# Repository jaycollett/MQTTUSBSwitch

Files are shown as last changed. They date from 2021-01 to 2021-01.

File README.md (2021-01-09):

# MQTTUSBSwitch
 

MQTT Enabled USB Switch to remotely connect/disconnect USB devices. This firmware and hardware attempts to mimic the actual pin connect/disconnect sequence that occurs when physically inserting or removing a USB plug. The board uses USB 3.0 connectors but only supports USB 2.0. Future versions will correctly switch the extra SS data pins so it will support USB 3.0. 

# Schematic 
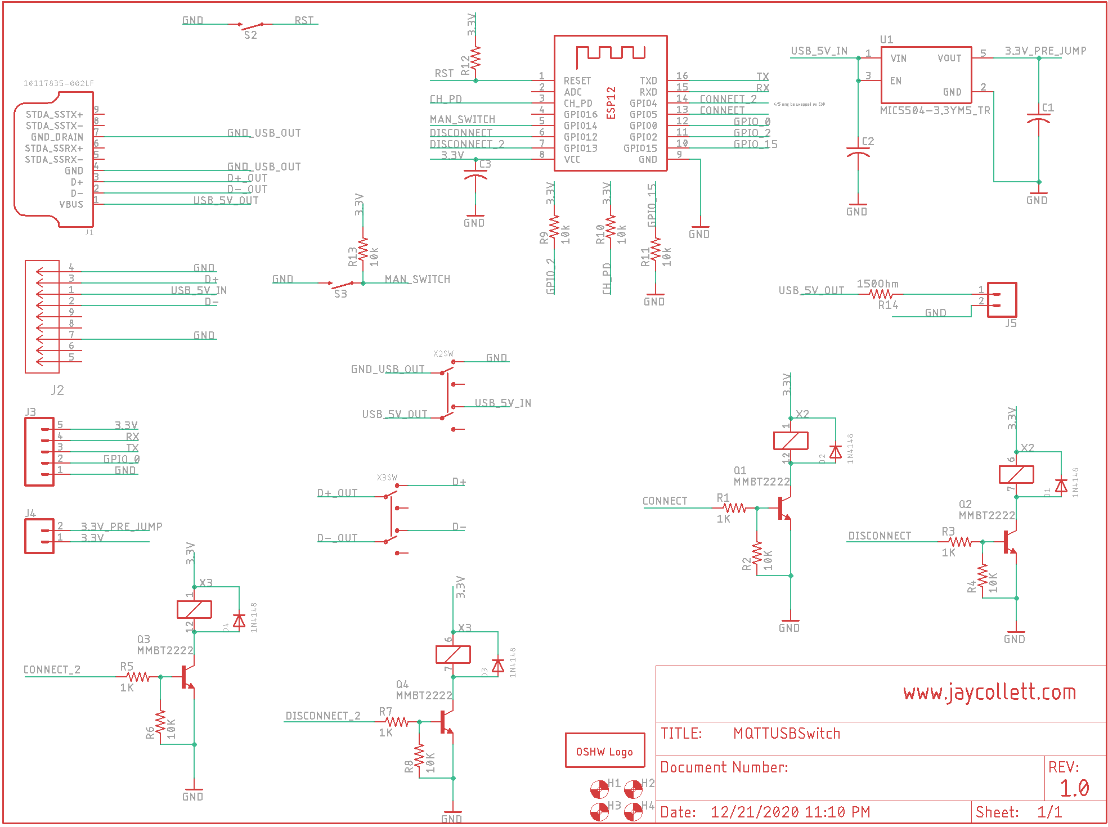
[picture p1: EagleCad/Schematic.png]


# Board 
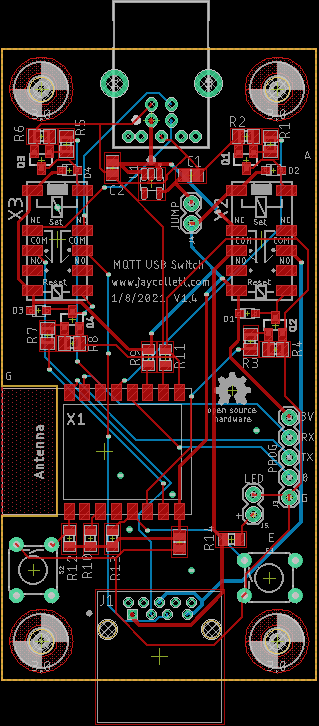
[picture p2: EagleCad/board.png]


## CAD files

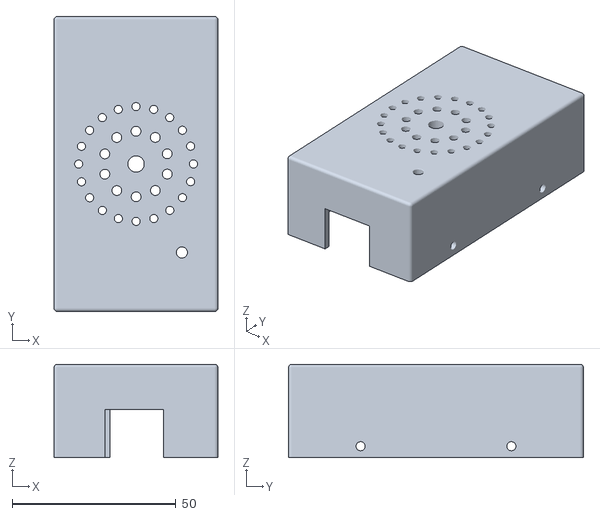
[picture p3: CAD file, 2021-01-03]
Project Enclosure/MQTTUSBSwitchCaseTopv2.stl
50.0 x 90.0 x 28.5

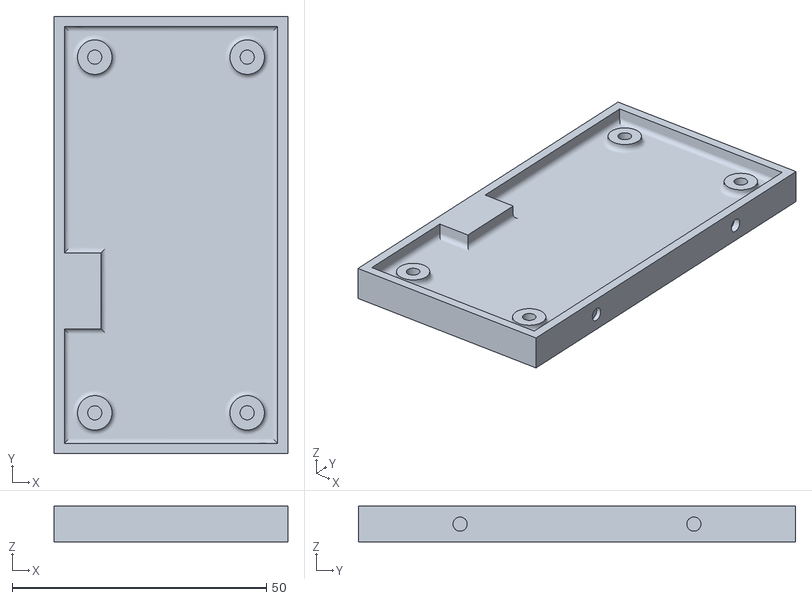
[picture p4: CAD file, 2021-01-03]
Project Enclosure/MQTTUSBSwitchCaseBottomv2.stl
46.0 x 86.0 x 7.05

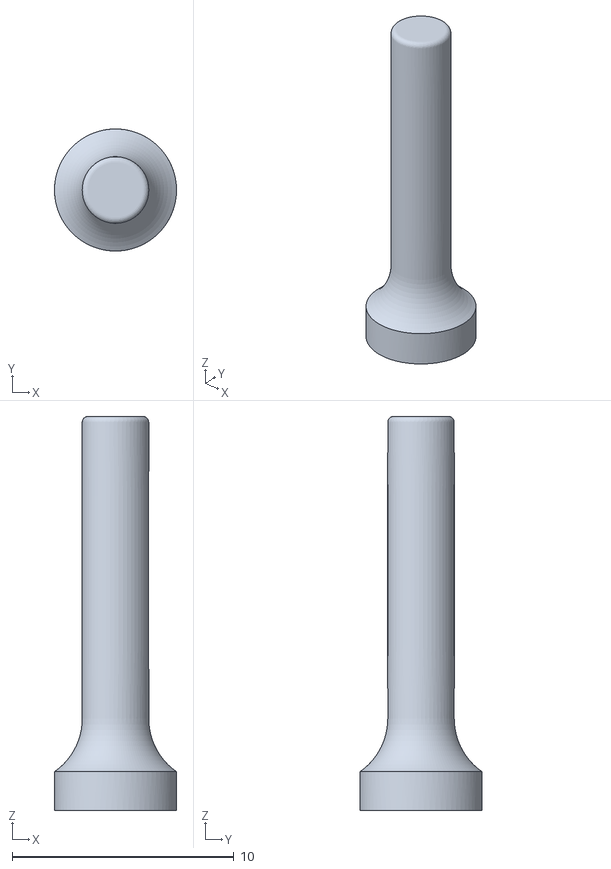
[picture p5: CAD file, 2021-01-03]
Project Enclosure/MQTTUSBSwitchPlunger.stl
5.50 x 5.50 x 17.7

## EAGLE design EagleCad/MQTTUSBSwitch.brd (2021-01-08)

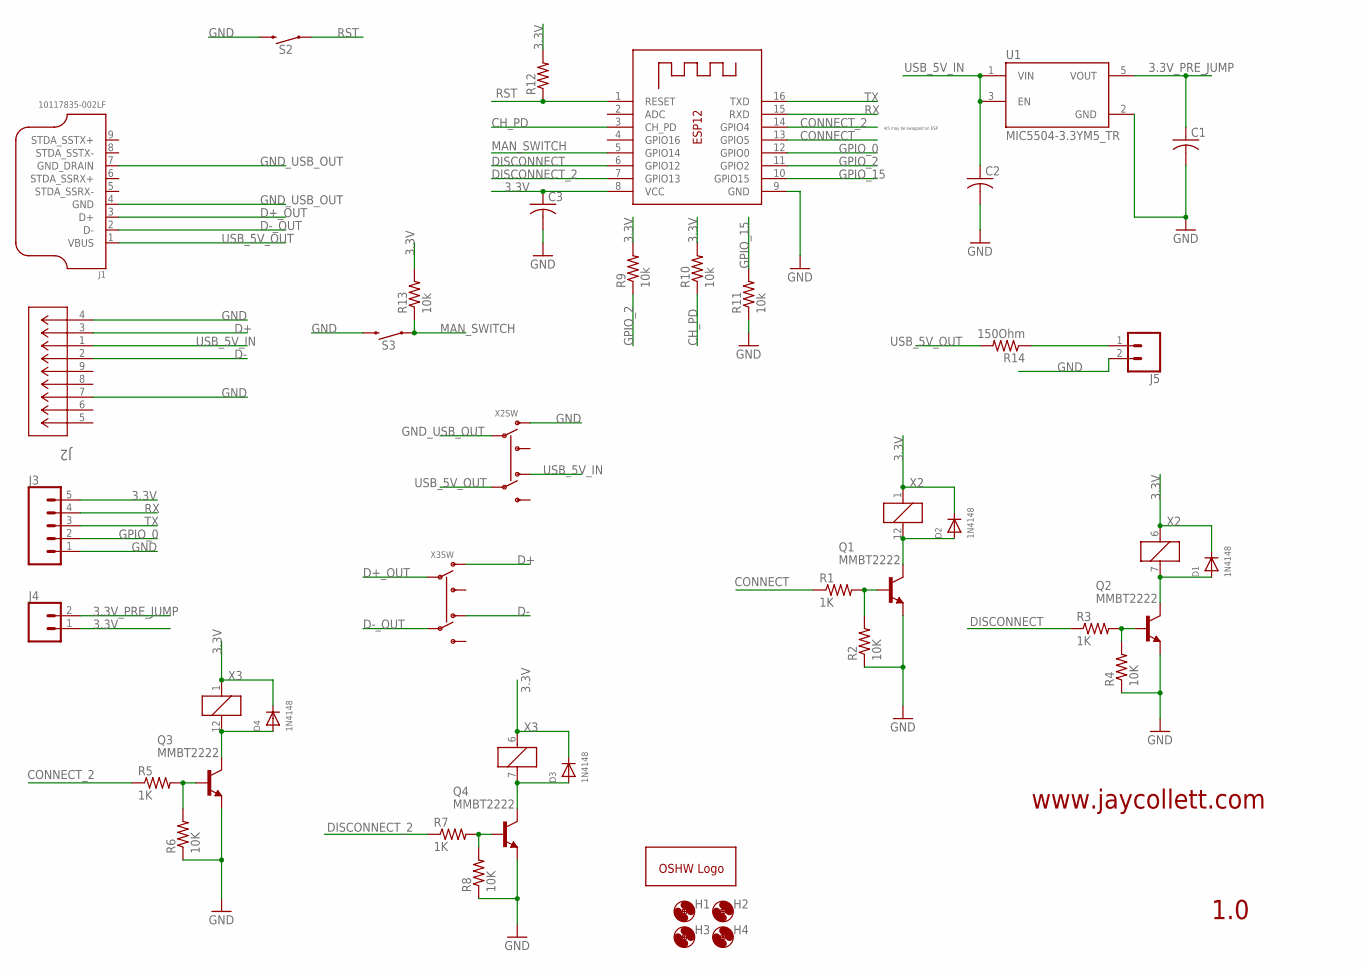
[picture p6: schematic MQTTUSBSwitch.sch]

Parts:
C1, C2, C3: C-USC0805; C0805
D1, D2, D3, D4: 1N4148; SOD-323F
GOLD_ORB_SM1: OSHWLOGOLOGO5MM; OSHW_5MM
H1, H2, H3, H4: MOUNT-HOLE3.0; 3,0
J1: 10117835-002LF; FCI_10117835-002LF
J2: GSB4211311WEU; CONN9_1311WEU_AMP
J3: CONN_05; 1X05
J4, J5: CONN_02; 1X02
Q1, Q2, Q3, Q4: MMBT2222; SOT23-BEC
R1, R3, R5, R7: 1K; M0805
R2, R4, R6, R8: 10K; M0805
R9, R10, R11, R13: 10k; R0805
R12: R-US_R0805; R0805
R14: 150Ohm; R0805
S2, S3: MOMENTARY-SWITCH-SPST-PTH-6.0MM-KIT; TACTILE_SWITCH_PTH_6.0MM_KIT
U1: MIC5504-3.3YM5_TR; SOT95P280X145-5N
X1: ESP-12
X2, X3: MICROBUILDER_RELAY_LATCHINGEE2NUH; MICROBUILDER_RELAY_EE2_LATCH

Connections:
3.3V: C3.1, D1.C, D2.C, D3.C, D4.C, J3.5, J4.1, R9.2, R10.2, R12.2, R13.2, X1.8 (VCC), X2.1, X2.6 (1), X3.1, X3.6 (1)
3.3V_PRE_JUMP: C1.1, J4.2, U1.5 (VOUT)
CH_PD: R10.1, X1.3 (CH_PD)
CONNECT: R1.1, X1.13 (GPIO5)
CONNECT_2: R5.1, X1.14 (GPIO4)
D+: J2.3, X3.10 (O1)
D+_OUT: J1.3 (D+), X3.9 (P1)
D-: J2.2, X3.3 (O2)
D-_OUT: J1.2 (D-), X3.4 (P2)
DISCONNECT: R3.1, X1.6 (GPIO12)
DISCONNECT_2: R7.1, X1.7 (GPIO13)
GND: C1.2, C2.2, C3.2, J2.4, J2.7, J3.1, J5.2, Q1.E, Q2.E, Q3.E, Q4.E, R2.1, R4.1, R6.1, R8.1, R11.1, S2.3 (2), S3.3 (2), U1.2 (GND), X1.9 (GND), X2.10 (O1)
GND_USB_OUT: J1.4 (GND), J1.7 (GND_DRAIN), X2.9 (P1)
GPIO_0: J3.2, X1.12 (GPIO0)
GPIO_2: R9.1, X1.11 (GPIO2)
GPIO_15: R11.2, X1.10 (GPIO15)
MAN_SWITCH: R13.1, S3.1, X1.5 (GPIO14)
unnamed: J5.1, R14.1
unnamed: D2.A, Q1.C, X2.12 (2)
unnamed: D1.A, Q2.C, X2.7 (2)
unnamed: Q1.B, R1.2, R2.2
unnamed: Q2.B, R3.2, R4.2
unnamed: D4.A, Q3.C, X3.12 (2)
unnamed: D3.A, Q4.C, X3.7 (2)
unnamed: Q3.B, R5.2, R6.2
unnamed: Q4.B, R7.2, R8.2
RST: R12.1, S2.1, X1.1 (RESET)
RX: J3.4, X1.15 (RXD)
TX: J3.3, X1.16 (TXD)
USB_5V_IN: C2.1, J2.1, U1.1 (VIN), U1.3 (EN), X2.3 (O2)
USB_5V_OUT: J1.1 (VBUS), R14.2, X2.4 (P2)

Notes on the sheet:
1.0
www.jaycollett.com
4/5 may be swapped on ESP

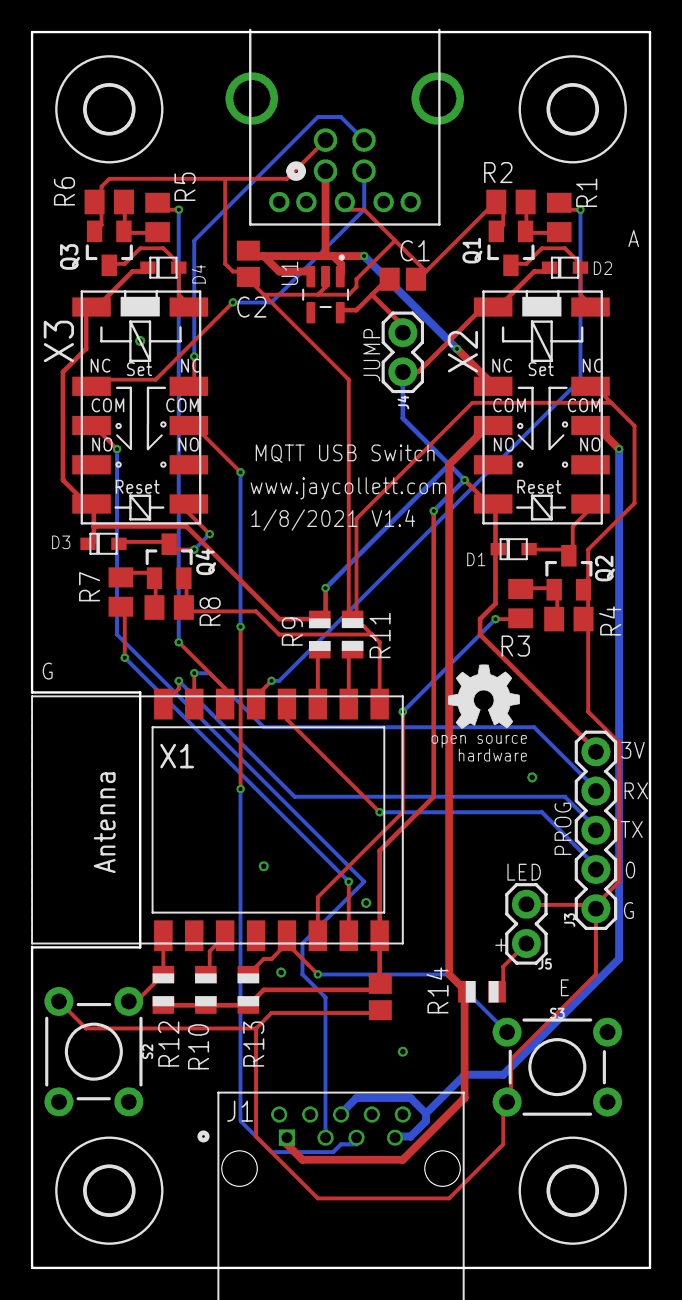
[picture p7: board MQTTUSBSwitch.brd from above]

Board: 2 copper layers, 40.0 x 80.0 mm, 41 parts (0 on the bottom side), 31 nets.

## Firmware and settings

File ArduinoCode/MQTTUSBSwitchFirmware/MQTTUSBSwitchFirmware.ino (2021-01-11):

// *******************************************************************************
//
// Ultimate Foosball Table Firmware v1.0 (12/24/2020)
//
// Firmware for my custom built USB Switch which has MQTT support
//
// Written by Jay Collett (jay AT jaycollett.com)
// http://www.jaycollett.com
//
// Additional unmodified libraries used (non-Arduino):
// WifiManager (https://github.com/tzapu/WiFiManager)
//
// This code is licensed under the MIT license.
//
// *******************************************************************************
#include <ESP8266WiFi.h>          //https://github.com/esp8266/Arduino
#include <DNSServer.h>
#include <ESP8266WebServer.h>
#include <WiFiManager.h>          //https://github.com/tzapu/WiFiManager
#include <PubSubClient.h>         //https://github.com/knolleary/pubsubclient
#include <ArduinoJson.h>          //https://arduinojson.org/

#define DEBUG

// Setup our debug printing
#ifdef DEBUG
#define debug(x)     Serial.print(x)
#define debugln(x)   Serial.println(x)
#else
#define debug(x)     // define empty, so macro does nothing
#define debugln(x)
#endif

const char    fmversion[]     = "v1.4";                         // firmware version
const char    mqtt_server[]   = "ha.collett.us";                // server name for mqtt
const char    mqtt_username[] = "mqtt_user_collett";            // username for MQTT broker (USE ONE)
const char    mqtt_password[] = "gabriel03ana08";               // password for MQTT broker
const char    mqtt_clientid[] = "mqttUsbSwitch";                // client id for connections to MQTT broker
const String  mqtt_out_topic  = "mqttUSBSwitch/stats/switch";   // the full topic for the publishing of data
const String  mqtt_in_topic   = "mqttUSBSwitch/cmd/switch";     // the full topic for the subscription
const String  mqtt_att_topic  = "mqttUSBSwitch/attributes";     // the full topic for posting attributes for this device

// Connect/Disconnect pins are incorrect in schematic based on the NO/CL position of the relays, adjusting in the firmware
#define powerConnectPin        12 //GPIO12
#define powerDisconnectPin     5  //GPIO4
#define dataConnectPin         13 //GPIO13
#define dataDisconnectPin      4  //GPIO4
#define manualSwitchButtonPin  14 //GPIO14

// keep track of our switch status (defaults on boot to off, and we make sure the switch is turned off)
String switchStatus = "off";

// configure a buffer to be used by arduinojson to post device attributes
char  MQTTMessageBuffer[256];

// configure our json static document with 256 bytes of space (pubsubclient is defaulted to max message of 256 bytes)
StaticJsonDocument<256> MQTTAttributesJSON;

// init our WiFi client object
WiFiClient espWiFiClient;

// init our mqtt client
PubSubClient client(espWiFiClient);


// ************************************************************************************************
//
//                                            Setup Method
//
// ************************************************************************************************
void setup() {
  // Setup the hw serial for the feather, used for debug...
#ifdef DEBUG
  Serial.begin(115200);
#endif

  //WiFiManager
  //Local intialization. Once its business is done, there is no need to keep it around
  WiFiManager wifiManager;

  //wifiManager.resetSettings(); //allows you to reset the stored config, would only use once then reflash with it
  // commented out

  //set callback that gets called when connecting to previous WiFi fails, and enters Access Point mode
  wifiManager.setAPCallback(configModeCallback);

  // set timeout for AP mode if can't connect to WiFi, if it times out, it'll reset the ESP, we set five minutes
  wifiManager.setConfigPortalTimeout(300);
  
  //fetches ssid and pass and tries to connect
  //if it does not connect it starts an access point
  //and goes into a blocking loop awaiting configuration
  if (!wifiManager.autoConnect()) {
    debugln("failed to connect and hit timeout");
    //reset and try again, or maybe put it to deep sleep
    ESP.reset();
    delay(1000);
  }

  // now we have a working network, configure MQTT
  client.setServer(mqtt_server, 1883);
  client.setCallback(mqttSubscriptionMessage);

  //define io pin use
  pinMode(BUILTIN_LED, OUTPUT);
  pinMode(powerConnectPin, OUTPUT);
  pinMode(powerDisconnectPin, OUTPUT);
  pinMode(dataConnectPin, OUTPUT);
  pinMode(dataDisconnectPin, OUTPUT);
  pinMode(manualSwitchButtonPin, INPUT);

  // set default status of pins on startup
  digitalWrite(BUILTIN_LED, HIGH); //high turns it off..
  digitalWrite(powerConnectPin, LOW);
  digitalWrite(powerDisconnectPin, LOW);
  digitalWrite(dataConnectPin, LOW);
  digitalWrite(dataDisconnectPin, LOW);

  // start off in a disconnected state and update mqtt server
  disconnectUSB();

  // setup our const firmware version in our MQTT JSON document
  MQTTAttributesJSON["FirmwareVersion"] = fmversion;

  // keep track of what caused us to take action, either MQTT message, manual button push, or device reset
  MQTTAttributesJSON["LastActionBy"] = "device_reset";
}

// ************************************************************************************************
//
//                                          Loop Method
//
// ************************************************************************************************
void loop() {

  if (!client.connected()) {
    reconnect();
  }

  // check to see if the manual switch button was pushed with software debounce
  if (digitalRead(manualSwitchButtonPin) == LOW) {
    debugln("Switch is low waiting, 100ms");
    delay(100);
    if (digitalRead(manualSwitchButtonPin) == LOW) {
      // switch the relays as the user requested
      debugln("Switching...");
      MQTTAttributesJSON["LastActionBy"] = "manual_button";
      if (switchStatus.equalsIgnoreCase("on")) {
        debugln("we are on, switching off...");
        // turn off the switch
        disconnectUSB();
      } else {
        debugln("we are off, switching on...");
        // connect as we are currently disconnected
        connectUSB();
      }
    }
  }

  // required call to ensure all MQTT messages are processed (in or out)
  client.loop();
}



// !#!#!#!#!#!#!#!#!#!#!#!#!#!#!#!#!#!#!#!#!#!#!#!#!#!#!#!#!#!#!#!#!#!#!#!#!#!#!#!#!#!#!#!#!#!#!#!#
//
//                                    Supporting methods below
//
// !#!#!#!#!#!#!#!#!#!#!#!#!#!#!#!#!#!#!#!#!#!#!#!#!#!#!#!#!#!#!#!#!#!#!#!#!#!#!#!#!#!#!#!#!#!#!#!#



// **************************************************************************
// Method to deal with messages we get on topics we are subscribed to
// **************************************************************************
void mqttSubscriptionMessage(char* topic, byte* payload, unsigned int length) {
  debug("Message arrived [");
  debug(topic);
  debug("] ");
  String payloadString = "";

  for (int i = 0; i < length; i++) {
    debug((char)payload[i]);
    payloadString += (char)payload[i];
  }

  debugln();
  debug("Payload string is: [");
  debug(payloadString);
  debugln("]");

  // Switch on the LED if an 1 was received as first character
  if (payloadString.equalsIgnoreCase("on")) {
    // update our value for the last action by topic
    MQTTAttributesJSON["LastActionBy"] = "mqtt_message";
    // switch the usb lines to connect everything
    connectUSB();
  }
  else if (payloadString.equalsIgnoreCase("off")) {
    // update our value for the last action by topic
    MQTTAttributesJSON["LastActionBy"] = "mqtt_message";
    // switch the usb lines to disconnect everything
    disconnectUSB();
  }

  // finally, let's publish the current state of our system back to the MQTT broker
  publishMQTTData();
}

// **************************************************************************
// Method to handle publishing MQTT our data to server
// **************************************************************************
void publishMQTTData() {
  client.publish(mqtt_out_topic.c_str(), switchStatus.c_str());
  char buffer[256];
  size_t n = serializeJson(MQTTAttributesJSON, buffer);
  client.publish(mqtt_att_topic.c_str(), buffer, n);
}

// **************************************************************************
// Method to handle configuration mode of WiFiManager
// **************************************************************************
void configModeCallback (WiFiManager *myWiFiManager) {
  debugln("Entered config mode");
  debugln(WiFi.softAPIP());

  //if you used auto generated SSID, print it
  debugln(myWiFiManager->getConfigPortalSSID());
}

// **************************************************************************
// Method to handle the (re)connection of our client to the MQTT server
// **************************************************************************
void reconnect() {
  // Loop until we're reconnected
  while (!client.connected()) {
    debug("Attempting MQTT connection...");
    // Attempt to connect
    if (client.connect(mqtt_clientid, mqtt_username, mqtt_password)) {
      debugln("connected");

      // Once connected, publish our data...
      publishMQTTData();

      // ... and resubscribe
      if (!client.subscribe(mqtt_in_topic.c_str())) {
        debugln("Failed to subscribe to topic");
      }
    } else {
      debug("failed, rc=");
      debug(client.state());
      debugln(" try again in 5 seconds");
      // Wait 5 seconds before retrying
      delay(5000);
    }
  }
}

// **************************************************************************
// Method to handle the CONNECTION of the USB interface
// **************************************************************************
void connectUSB() {
  // first we must connect the power and gnd lines
  digitalWrite(powerConnectPin, HIGH);
  delay(50);
  digitalWrite(powerConnectPin, LOW);

  // now that the power lines are connected, we wait a fraction of a second
  delay(50);

  // now we can disconnect power and gnd
  digitalWrite(dataConnectPin, HIGH);
  delay(50);
  digitalWrite(dataConnectPin, LOW);

  // set our onboard LED status to on
  digitalWrite(BUILTIN_LED, LOW);   // Turn the LED on (Note that LOW is the voltage level

  // update our tracking var
  switchStatus = "on";

  // Once connected, publish our data...
  publishMQTTData();
}

// **************************************************************************
// Method to handle the DISCONNECTION of the USB interface
// **************************************************************************
void disconnectUSB() {
  // first we must remove the data lines
  digitalWrite(dataConnectPin, HIGH);
  delay(50);
  digitalWrite(dataConnectPin, LOW);

  // now that the data lines are disconnected, we wait a fraction of a second
  delay(80);

  // now we can disconnect power and gnd
  digitalWrite(powerDisconnectPin, HIGH);
  delay(50);
  digitalWrite(powerDisconnectPin, LOW);

  // update our tracking var
  switchStatus = "off";

  // turn off our onboard LED indicator
  digitalWrite(BUILTIN_LED, HIGH);  // Turn the LED off by making the voltage HIGH

  // Once connected, publish our data...
  publishMQTTData();
}

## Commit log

2021-01-03 initial project commit
    [MQTTUSBSwitch.brd, MQTTUSBSwitch.sch, MQTTUSBSwitchCaseBottom.stl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]
2021-01-03 Update case enclosure to have two screws per side
    [MQTTUSBSwitchCaseBottom.stl, MQTTUSBSwitchCaseBottomv2.stl, MQTTUSBSwitchCaseTop.stl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]
2021-01-08 fix board issue with ground airwires and soldermask exposing ground plane
    [MQTTUSBSwitch.brd]
2021-01-08 Fix issue with firmware and disconnect method
    [MQTTUSBSwitchFirmware.ino]
2021-01-09 Fix the swapped pins for connect/disconnect of data and power
    [MQTTUSBSwitchFirmware.ino]
2021-01-09 add mqtt message and topic for why we switched (mqtt, manual switch, or device reset)
    [MQTTUSBSwitchFirmware.ino]
2021-01-09 rename arduino folder to remove space

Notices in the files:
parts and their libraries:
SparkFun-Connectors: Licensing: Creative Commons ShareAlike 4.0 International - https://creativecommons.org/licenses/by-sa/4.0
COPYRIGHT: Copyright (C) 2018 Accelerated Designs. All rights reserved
